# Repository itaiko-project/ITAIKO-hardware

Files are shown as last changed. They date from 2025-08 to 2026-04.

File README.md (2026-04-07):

<p align="center">
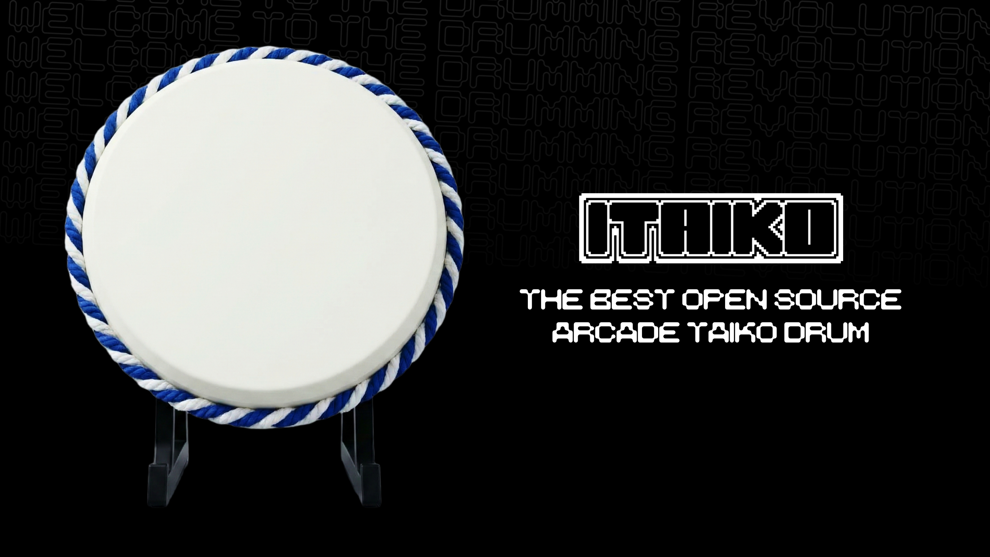
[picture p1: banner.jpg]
ITAIKO Banner
    
</p>

**ITAIKO** is an open-source, DIY drum controller for *Taiko no Tatsujin* and its simulators. 

Built for rhythm game enthusiasts who want to build an arcade-quality drum at home, or for those who want to update their older drum with a newer and better e-box, the **onigiri-con!**

This project is heavily inspired by, and builds upon the incredible groundwork laid by:
* [**ravinrabbid's DonCon2040**](https://github.com/ravinrabbid/DonCon2040) for the base firmware and console compatibility!
* [**kasashiki3's HIDtaiko**](https://github.com/kasasiki3/HIDtaiko) for the passive sensors cleanup cicuit!

---

## ✨ Features

* **Arcade-like accuracy:** The firmware has been modified with a simple but effective algorithm that provides near-perfect readings even on the cheapest sensors!
* **Low Latency:** The passive cleanup circuit only uses **two diodes** to improve the readablity of the sensors, and combined with the speed of the RP2040 provides super fast readings without any operational amplifiers and active electronics!
* [**Web Configurator:**](https://itaiko.com/) A web-usb based configurator that works on Chromium-based browsers and Firefox*, it supports auto updating, key remapping and includes a built-in drum tester inspired by [**the Zhong Taiko Controller Tester.**](https://tktest.taiko.ac/)
* **Multi-Platform Support:** It's compatible with PC, PS4**, Switch, Android, iOS and even PS3!
* **Fully Open Source:** From the drum, to the onigiri, you can easily 3D print, laser cut and build your own ITAIKO! **We provide the files for everything you'll ever need.**

>*On firefox you'll need to install a lightweight extension to enable WebUSB

>**On PS4 you'll need to provide your own Dualshock 4 Private keys to avoid the 8 minute timeout!
---

## 🎮 Compatibility

**ITAIKO** is designed to be plug-and-play across various platforms. Below is the current compatibility status:

| Platform | Status | Notes |
| :--- | :--- | :--- |
| **PC (Windows/Mac/Linux)** | 🟢 Native | Works instantly with osu!taiko, TJAPlayer3, Taiko Web, etc. Maps as a standard USB gamepad, keyboard or XInput device. |
| **Android / iOS** | 🟢 Native | Works via USB OTG adapter as a standard gamepad/keyboard! |
| **Nintendo Switch (Hori Switch mode)** | 🟢 Native | Spoofs the official HORI Taiko Drum controller. Plug into the dock and play. |
| **PlayStation 3** | ⚠️ Currently untested | Should work as a Dualshock 3. |
| **PlayStation 4 (Hori PS4 mode)** | 🟡 Requires Auth | To avoid restarting the e-box every 8 minutes, **you'll need to provide your own Dualshock 4 private keys** (You can drag-drop them in the web configurator!) |
| **PlayStation 5** | ⚠️ Currently untested | Should work on PS4 backward-compatible games. PS4 limitation still apply here. |

---

##  Hardware

To build your own ITAIKO, you will need a mix of 3D printed parts, basic electronics, and woodwork.

This section is a WIP and will change constantly untill we get the drum design finalized. 

> A full, detailed Bill of Materials (BOM) and assembly guide will be added soon.

---

## Getting Started

>WIP

---

## Credits & Acknowledgements

This project would not exist without the open-source rhythm gaming community. Massive thanks to:

**Kasashiki3**, which made non-amplified piezo readings  comparable to amplified boards!

**ravinrabbid** with his amazing firmware on which we built our upon.

**The Taiko home drumming community** for sharing precious data necessary for this project to come to life.

**Zhong and all the other drum makers** for making arcade accurate home drumming a reality.

---

## License

This project is licensed under the **Creative Commons Attribution-NonCommercial-ShareAlike 4.0 International License (CC BY-NC-SA 4.0)**.

To view a copy of this license, visit [https://creativecommons.org/licenses/by-nc-sa/4.0/](https://creativecommons.org/licenses/by-nc-sa/4.0/).

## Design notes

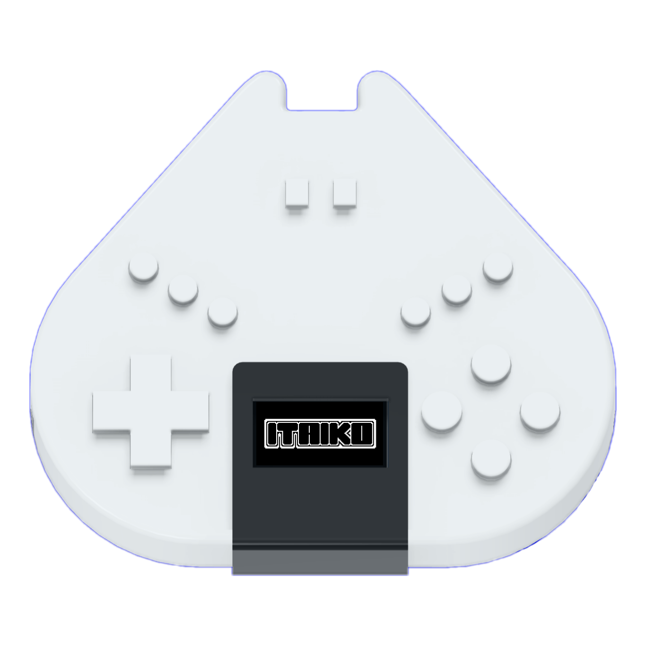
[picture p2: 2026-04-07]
onigiri.png

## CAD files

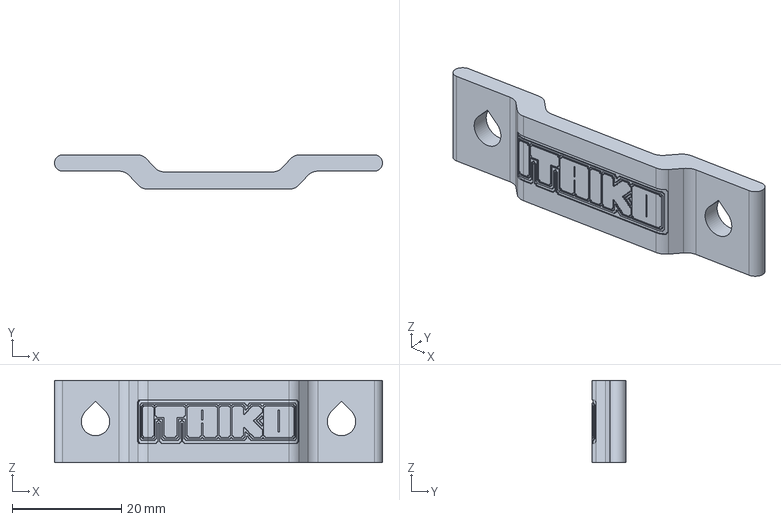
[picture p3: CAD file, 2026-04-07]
Drum/sensor_mount.step
60.0 x 6.30 x 15.0 mm

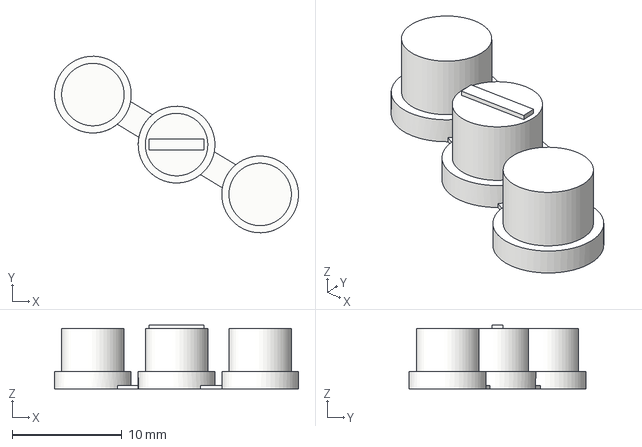
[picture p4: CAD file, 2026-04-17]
Onigiri-con/Buttons 3D Models/LEFT_BUTTONS.step
22.2 x 16.1 x 5.80 mm

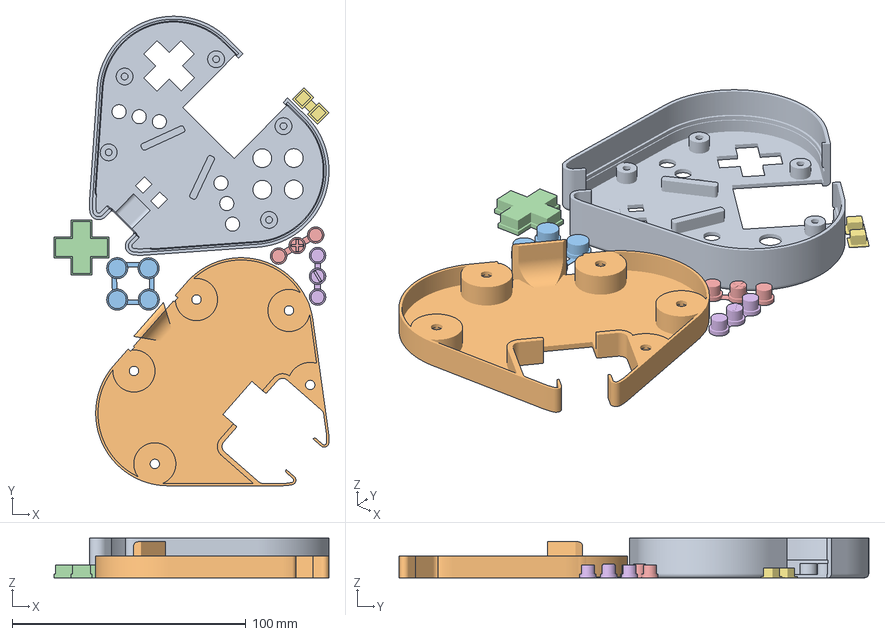
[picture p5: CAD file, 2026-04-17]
Onigiri-con/Everything ready to print.3mf
117.5 x 200.7 x 16.9 mm
UPPER_BODY_2.9MM_SCREWHOLES.step
LOWER_BODY.step
ACTION_BUTTONS.step
DPAD.step
RIGHT_BUTTONS.step
LEFT_BUTTONS.step
PICO_BUTTONS.step

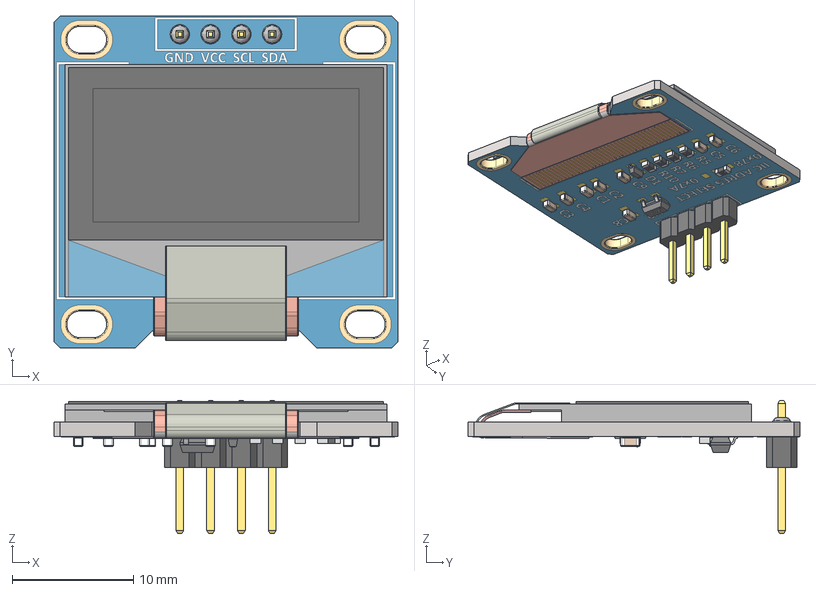
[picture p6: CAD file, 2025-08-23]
Onigiri-con/PCB_onigiricon/Models/ssd1306.stp
28.4 x 27.4 x 11.0 mm
SOT-23_TOR
RES_CR16_MTK_1 x 4
RES_CR16_MTK
SOD323F_DIO

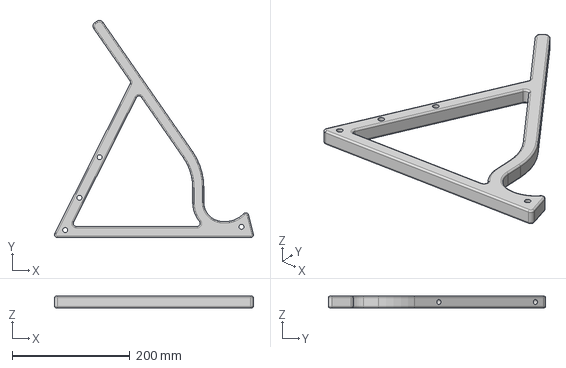
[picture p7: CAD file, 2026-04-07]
Drum/drum_stand_M8.step
338.0 x 368.9 x 20.0 mm

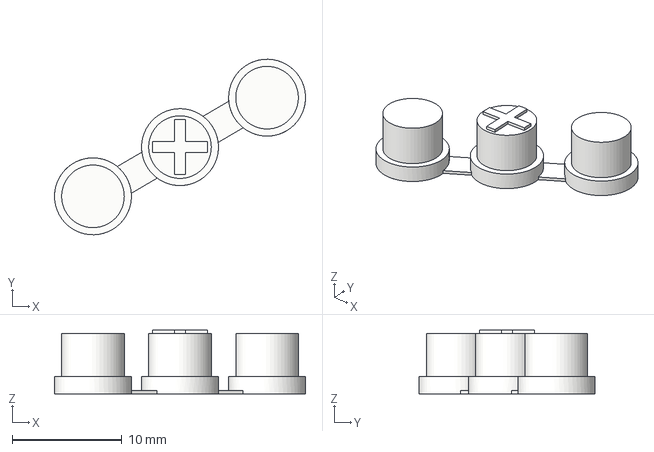
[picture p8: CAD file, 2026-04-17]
Onigiri-con/Buttons 3D Models/RIGHT_BUTTONS.step
22.8 x 16.0 x 5.80 mm

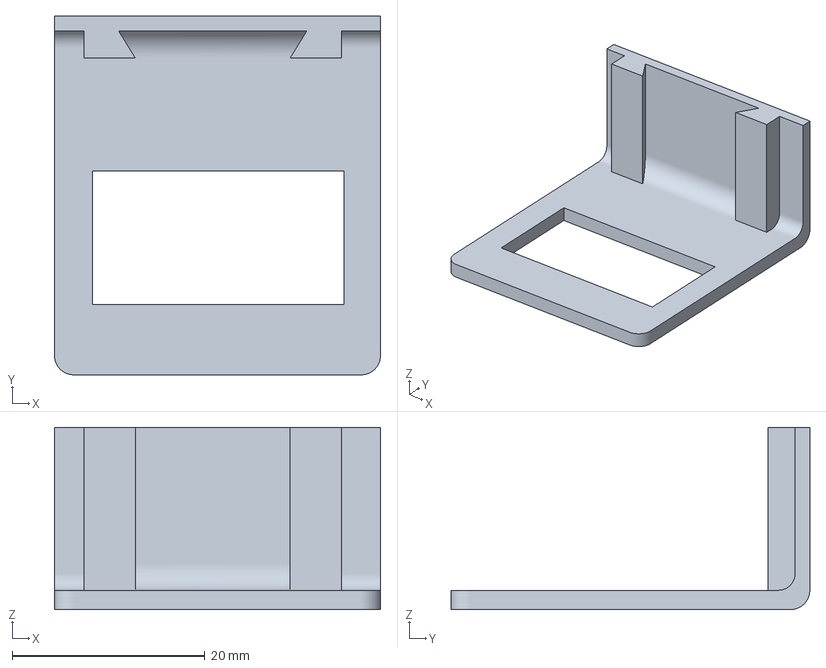
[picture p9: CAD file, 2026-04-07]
Onigiri-con/Oled cover.3mf
33.9 x 37.3 x 18.9 mm

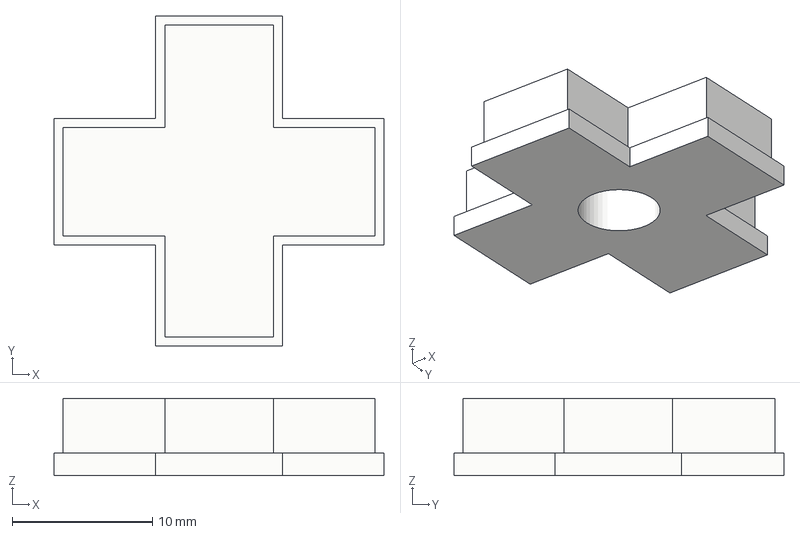
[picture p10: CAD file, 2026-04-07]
Onigiri-con/Buttons 3D Models/DPAD.step
23.5 x 23.5 x 5.50 mm

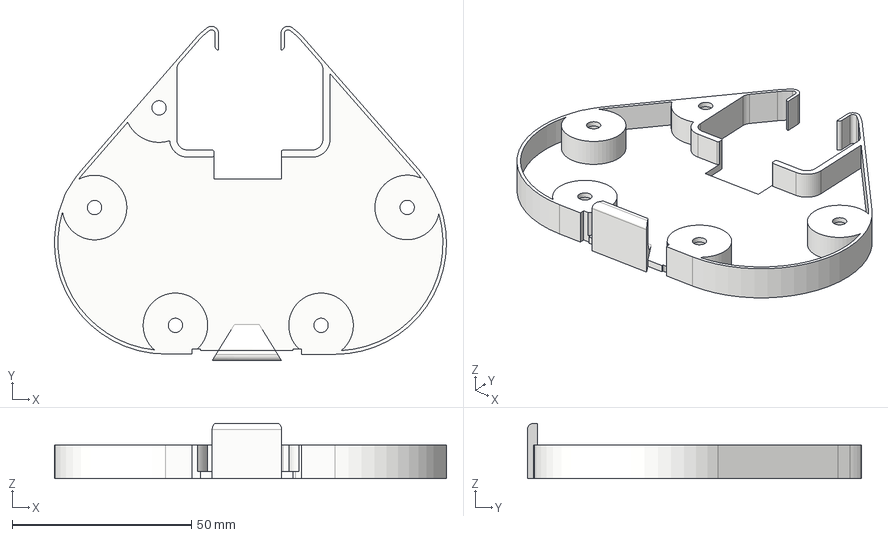
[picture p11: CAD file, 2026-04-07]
Onigiri-con/Shell 3D Models/LOWER_BODY.step
109.2 x 93.2 x 15.4 mm

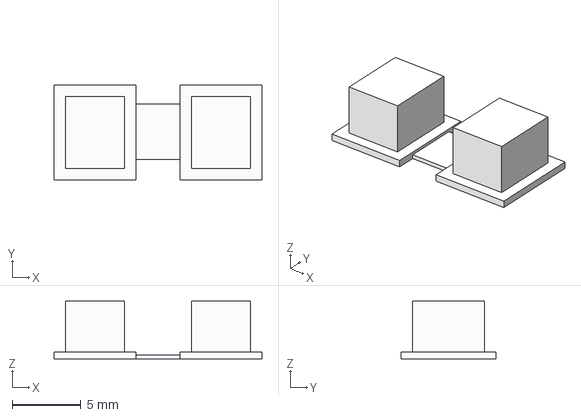
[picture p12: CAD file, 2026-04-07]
Onigiri-con/Buttons 3D Models/PICO_BUTTONS.step
15.2 x 6.93 x 4.21 mm

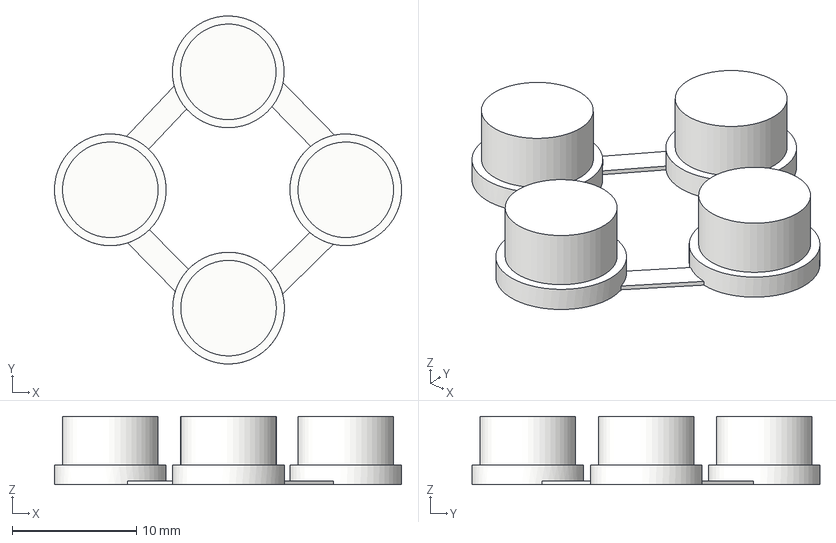
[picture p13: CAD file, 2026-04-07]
Onigiri-con/Buttons 3D Models/ACTION_BUTTONS.step
28.0 x 28.0 x 5.50 mm

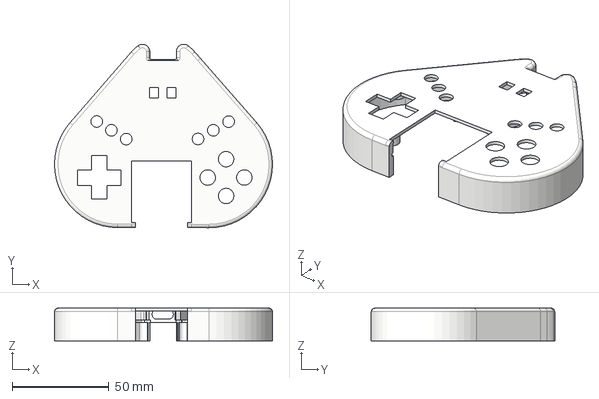
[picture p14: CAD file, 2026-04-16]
Onigiri-con/Shell 3D Models/UPPER_BODY_2.9MM_SCREWHOLES.step
112.8 x 95.0 x 16.9 mm

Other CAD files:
Onigiri-con/Shell 3D Models/OLED_COVER.step
Onigiri-con/Shell 3D Models/UPPER_BODY_3MM_SCREWHOLES.step

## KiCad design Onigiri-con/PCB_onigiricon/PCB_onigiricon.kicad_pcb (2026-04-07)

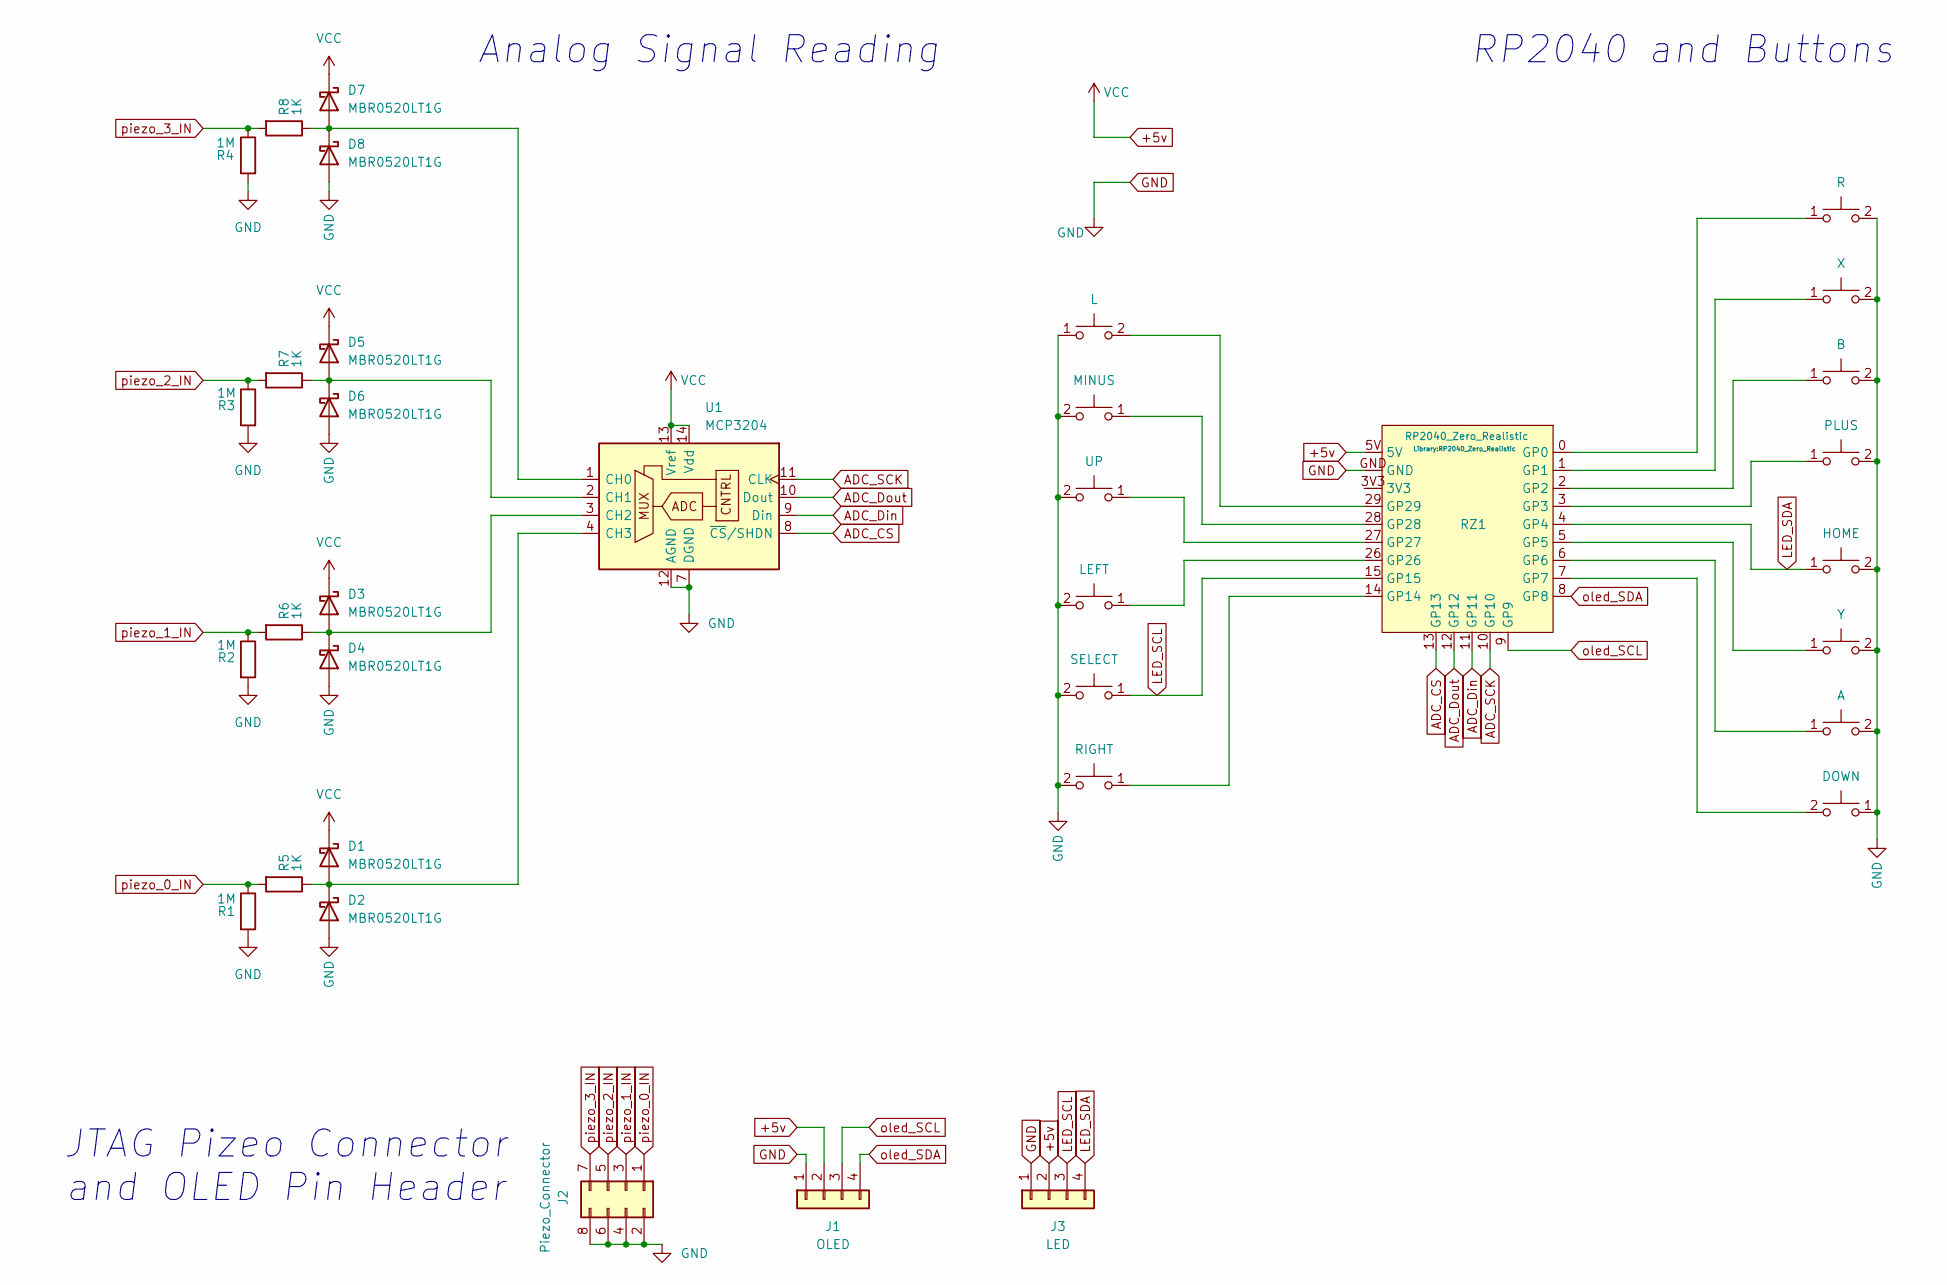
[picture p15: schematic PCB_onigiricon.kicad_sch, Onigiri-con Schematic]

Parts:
D1, D2, D3, D4, D5, D6, D7, D8: MBR0520LT1G; D_SOD-123
J1: OLED; PinSocket_1x04_P2.54mm_Vertical
J2: Piezo_Connector; IDC-Header_2x04_P2.54mm_Horizontal
J3: LED; PinSocket_1x04_P2.54mm_Vertical
R1, R2, R3, R4: 1M; R_0805_2012Metric
R5, R6, R7, R8: 1K; R_0805_2012Metric
RZ1: RP2040_Zero_Realistic
SW1: X; SW_SPST_CK_RS282G05A3
SW2: A; SW_SPST_CK_RS282G05A3
SW3: B; SW_SPST_CK_RS282G05A3
SW4: Y; SW_SPST_CK_RS282G05A3
SW5: PLUS; SW_SPST_CK_RS282G05A3
SW6: HOME; SW_SPST_CK_RS282G05A3
SW9: UP; SW_SPST_CK_RS282G05A3
SW10: LEFT; SW_SPST_CK_RS282G05A3
SW11: DOWN; SW_SPST_CK_RS282G05A3
SW12: RIGHT; SW_SPST_CK_RS282G05A3
SW13: MINUS; SW_SPST_CK_RS282G05A3
SW14: SELECT; SW_SPST_CK_RS282G05A3
SW15: R; SW_SPST_CK_RS282G05A3
SW16: L; SW_SPST_CK_RS282G05A3
U1: MCP3204; SOIC-14_3.9x8.7mm_P1.27mm

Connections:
+5v: D1.1 (K), D3.1 (K), D5.1 (K), D7.1 (K), J1.2, J3.2, RZ1.5V, U1.13 (Vref), U1.14 (Vdd)
ADC_CS: RZ1.13 (GP13), U1.8 (~CS/SHDN)
ADC_Din: RZ1.11 (GP11), U1.9 (Din)
ADC_Dout: RZ1.12 (GP12), U1.10 (Dout)
ADC_SCK: RZ1.10 (GP10), U1.11 (CLK)
GND: D2.2 (A), D4.2 (A), D6.2 (A), D8.2 (A), J1.1, J2.2, J2.4, J2.6, J2.8, J3.1, R1.2, R2.2, R3.2, R4.2, RZ1.GND, SW1.2 (D), SW2.2 (D), SW3.2 (D), SW4.2 (D), SW5.2 (D), SW6.2 (D), SW9.2 (D), SW10.2 (D), SW11.1 (C), SW12.2 (D), SW13.2 (D), SW14.2 (D), SW15.2 (D), SW16.1 (C), U1.7 (DGND), U1.12 (AGND)
LED_SCL: J3.3, RZ1.15 (GP15), SW14.1 (C)
LED_SDA: J3.4, RZ1.4 (GP4), SW6.1 (C)
unnamed: D1.2 (A), D2.1 (K), R5.1, U1.4 (CH3)
unnamed: D3.2 (A), D4.1 (K), R6.1, U1.3 (CH2)
unnamed: D5.2 (A), D6.1 (K), R7.1, U1.2 (CH1)
unnamed: D7.2 (A), D8.1 (K), R8.1, U1.1 (CH0)
unnamed: RZ1.0 (GP0), SW15.1 (C)
unnamed: RZ1.1 (GP1), SW1.1 (C)
unnamed: RZ1.2 (GP2), SW3.1 (C)
unnamed: RZ1.3 (GP3), SW5.1 (C)
unnamed: RZ1.5 (GP5), SW4.1 (C)
unnamed: RZ1.6 (GP6), SW2.1 (C)
unnamed: RZ1.7 (GP7), SW11.2 (D)
unnamed: RZ1.14 (GP14), SW12.1 (C)
unnamed: RZ1.26 (GP26), SW10.1 (C)
unnamed: RZ1.27 (GP27), SW9.1 (C)
unnamed: RZ1.28 (GP28), SW13.1 (C)
unnamed: RZ1.29 (GP29), SW16.2 (D)
oled_SCL: J1.3, RZ1.9 (GP9)
oled_SDA: J1.4, RZ1.8 (GP8)
piezo_0_IN: J2.1, R1.1, R5.2
piezo_1_IN: J2.3, R2.1, R6.2
piezo_2_IN: J2.5, R3.1, R7.2
piezo_3_IN: J2.7, R4.1, R8.2

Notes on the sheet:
RP2040 and Buttons
JTAG Pizeo Connector and OLED Pin Header
Analog Signal Reading

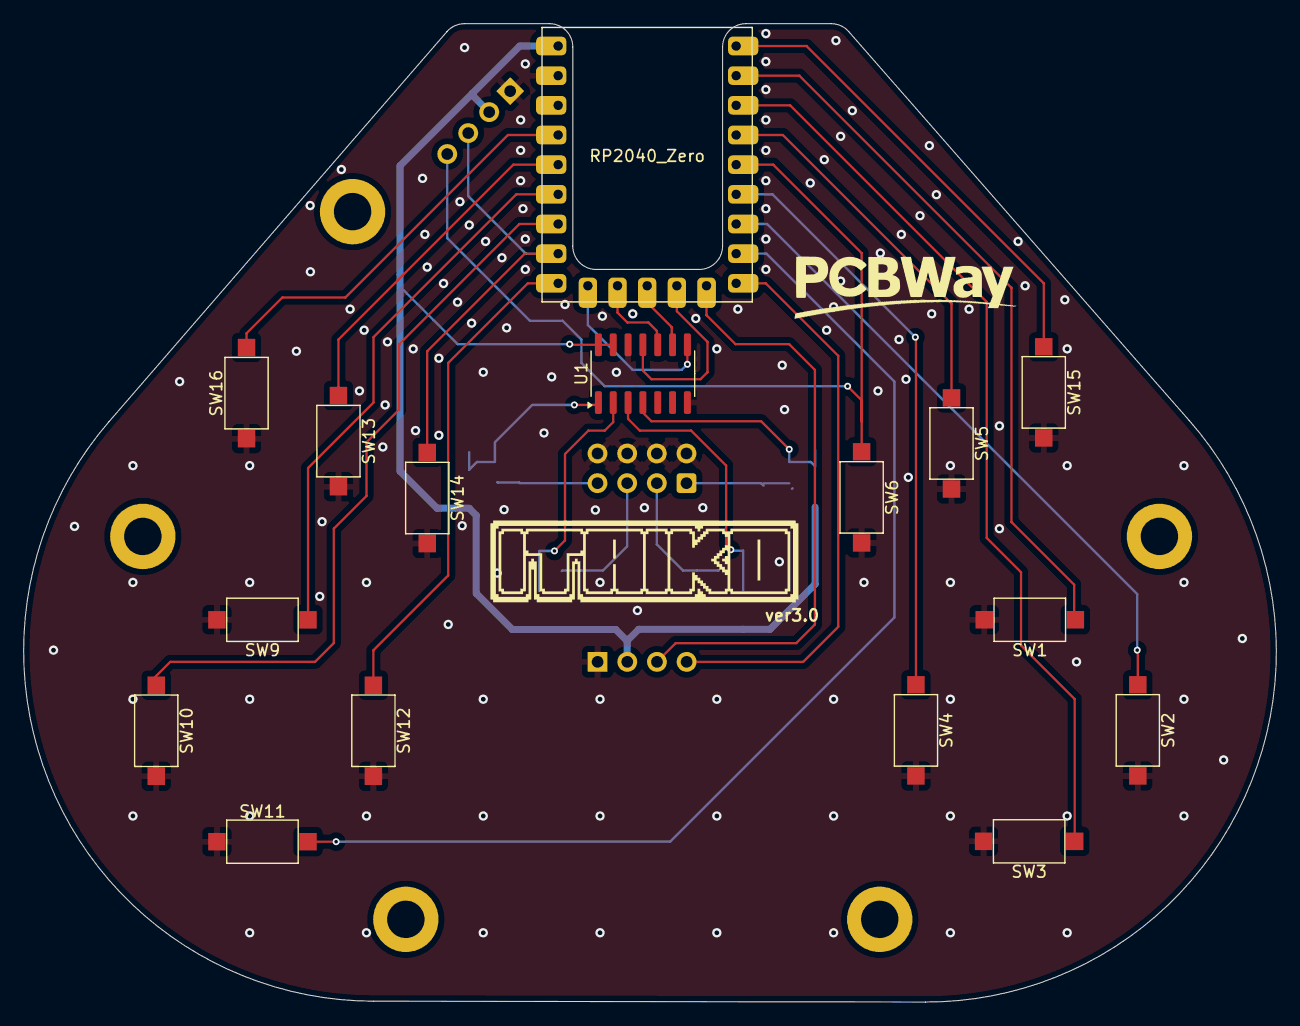
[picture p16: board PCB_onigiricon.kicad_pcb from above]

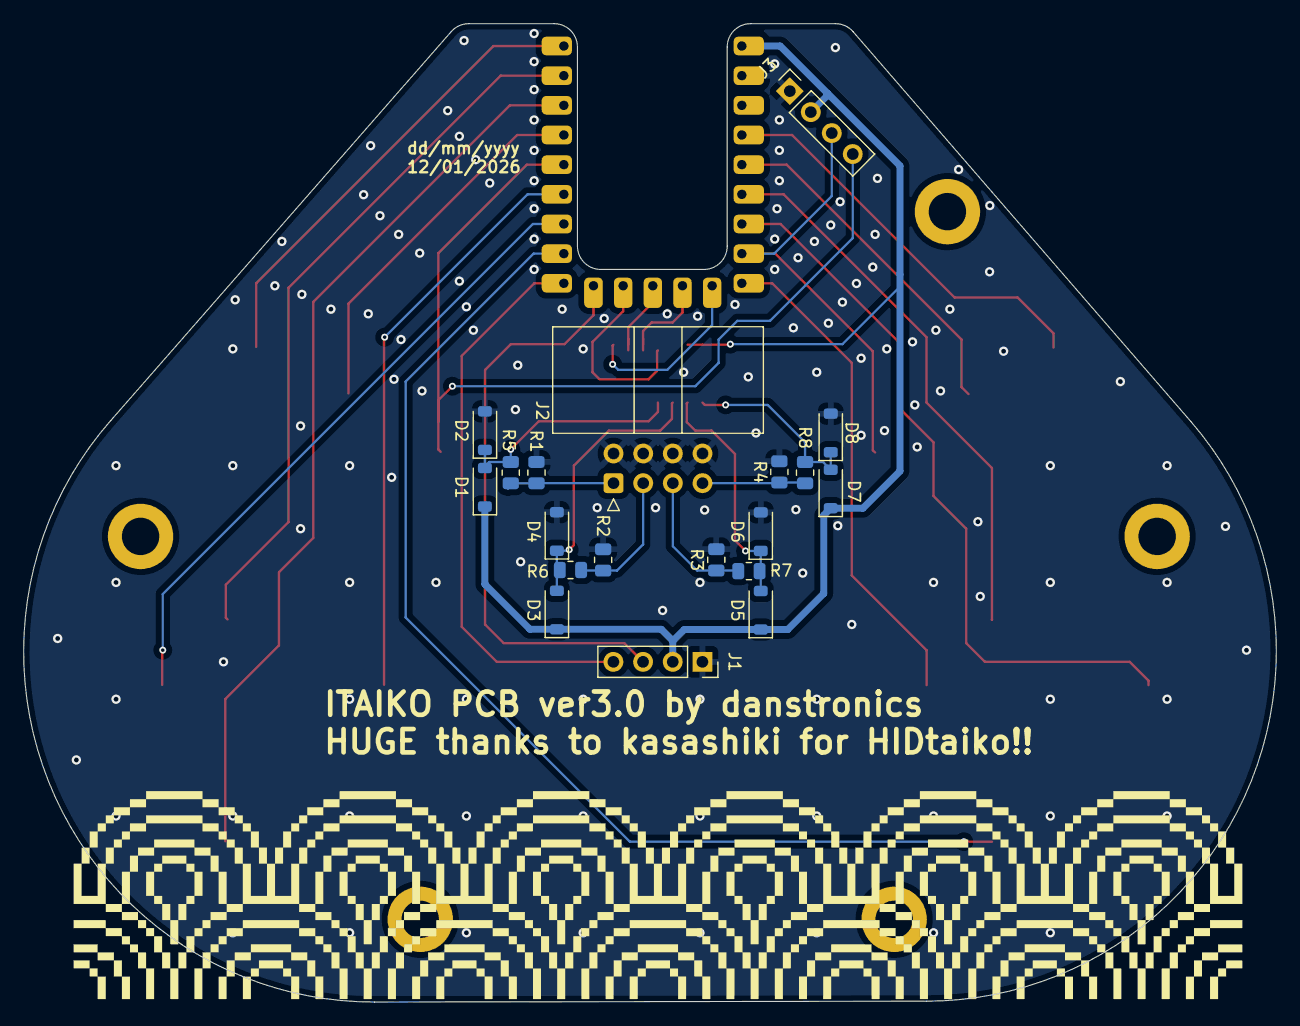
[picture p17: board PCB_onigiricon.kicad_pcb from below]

Board: 2 copper layers, 107.3 x 83.8 mm, 35 parts (19 on the bottom side), 30 nets.

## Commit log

2025-08-23 Removing everything non-ITAIKO
    [0.2.stl, 0.4.stl, 0.6.stl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]
2026-04-07 Updated the repo with the latest PCB and STEP files.
    Slowly making the project fully open source!
    [ACTION_BUTTONS.step, DPAD.step, Everything ready to print.3mf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]
2026-04-16 Added upper Onigiri-con shell with smaller holes for tighter screw fit!
    [UPPER_BODY_2.9MM_SCREWHOLES.step, UPPER_BODY_3MM_SCREWHOLES.step]
2026-04-17 Fixed raised + and - marks on the side buttons, updated the ready to print file with 2.9MM holes upper shell and updated + - buttons
    [Everything ready to print.3mf, LEFT_BUTTONS.step, RIGHT_BUTTONS.step]
